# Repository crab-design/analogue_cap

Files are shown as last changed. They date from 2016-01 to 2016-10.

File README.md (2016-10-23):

##What is it?

The analogue cap was designed in response to the release of the raspberry pi zero. For a low cost it helps to break out the analogue outputs from the zero. The analogue ports it provides are stereo audio, composite and VGA. All connectors are aligned to the same edge as the Zero's existing connectors. The board is ideal if you want to utilize a computer monitor, especially if it has built in speakers like many 'multimedia' TFT screens that now cost very little second hand.

Excluding the composite output it will also work on any Raspberry Pi that has the 40 pin GPIO header [ Raspberry Pi A/B+ and the Raspberry Pi B2 ] It
It is a kit

To make it as cheap as possible and easy to adapt for different purposes it is a kit / bare PCB that uses only through-hole components. Due to a lack of space all components are folded this may make it a little fiddly to construct if you have less experience but it is not too hard.

What this means though is that you can choose which way up the cap is mounted, if you what the VGA or not and if you are building into an enclosure the pads can be directly soldered.

the BOM is as follows

    1 x VGA socket
    1 x RCA phono
    1 x 3.5mm Socket
    1 x 40 way socket
    1 x 4 way socket
    1 x PCB
    4 x diodes
    24 x Resistors
    4 x Capacitors

##Enabling the outputs

Please see the setup folder for more information

Due to space and cost the cap does not have auto recognition EEPROM as defined by the HAT specification. It has to be set up by editing the config.txt and adding files to the /boot/ partition.

For VGA it uses Gert van loo's VGA666 hack which uses a passive resistor network to perform the Digital to Analogue conversion. The pins it uses are mapped differently (mode 6 instead of 5) to allow for the audio to also be broken out of the GPIO header. To activate VGA an 'overlay' has to be added to the configuration files of the boot partition. These will be provided in the Github repository.

Analogue audio is the same as the circuit on the Raspberry Pi B+ schematic, but instead the output comes from the GPIO. To activate another 'overlay' is used that comes with the default Rasbian distribution (pwm-2chan-overlay) If this and the VGA is activated only 4 GPIO pins will remain.

The composite is simply an extension of the new breakout pins next to the the Zero's GPIO header, it is connected by its own socket when the cap is pushed on.

The parts activated are up to the user by simply disabling and enabling parts in the config.txt file.

Thankyou for looking, I hope someone will find it useful especially those with lots of old VGA screens hanging around!

Copyright © 2016 Clacktronics

This document and the related files are free: you can redistribute it and/or modify it under the terms of the GNU General Public License as published by the Free Software Foundation, either version 3 of the License, or (at your option) any later version.

This program is distributed in the hope that it will be useful, but WITHOUT ANY WARRANTY; without even the implied warranty of MERCHANTABILITY or FITNESS FOR A PARTICULAR PURPOSE.  See the GNU General Public License for more details.

You should have received a copy of the GNU General Public License along with this document.  If not, see <http://www.gnu.org/licenses/>.

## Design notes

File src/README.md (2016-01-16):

## VGA666 overlays

These files are a copy of the vga666 overlay found in the Raspberry Pi repository [vga666-overlay.dts](https://github.com/raspberrypi/linux/blob/rpi-4.1.y/arch/arm/boot/dts/overlays/vga666-overlay.dts), they have had the pins changed to match the different modes of the GPIO LCD mode as used by the VGA666 board and this analogue board.

information about compiling and editing them can be found on the [Raspberry Pi website](https://www.raspberrypi.org/documentation/configuration/device-tree.md)

to compile (in Rasbian) use the following steps, install the dtc-compiler

`sudo apt-get install device-tree-compiler`

then use the following command `-I dts` defines the source type `-O is the output type` then `-o output.dtb` is the output file you want to make and then the `source.dts` is the file you want to compile.

`dtc -I dts -O dtb -o output.dtb source.dts`

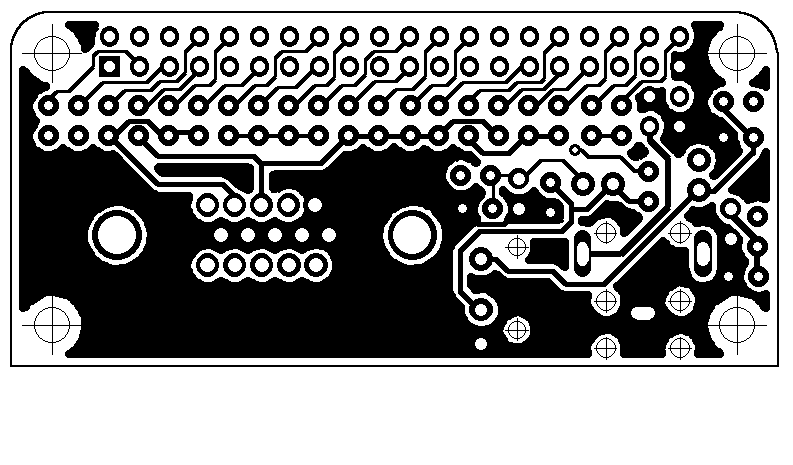
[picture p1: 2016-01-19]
PCB/bitmap/top.bmp

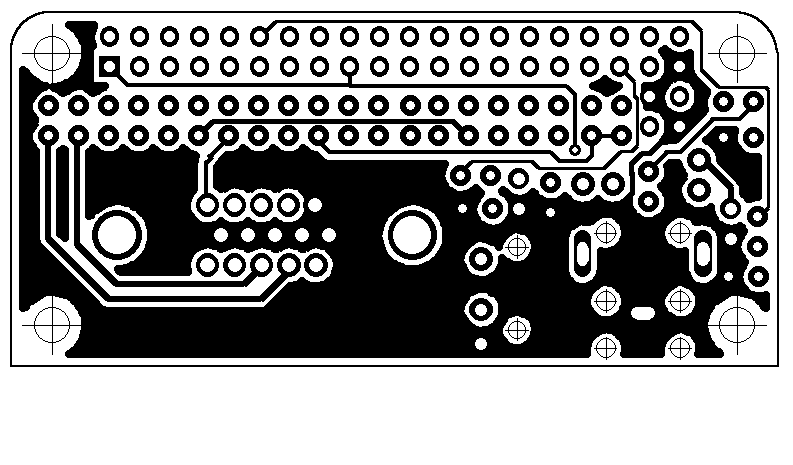
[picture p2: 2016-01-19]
PCB/bitmap/bottom.bmp

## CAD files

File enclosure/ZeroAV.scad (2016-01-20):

// Pi
//translate([0,0,1.6])
//color([0.2,1,0,1])
//roundedRect([65, 30, 1.6], 5, $fn=12);

// Case

color([1,1,1,1])
difference(){
roundedRect([67, 32, 20], 6, $fn=12);
translate([0,0,1.6])roundedRect([65, 30, 20], 5, $fn=12);

rotate([90,0,0])
translate([0,4,10])
{
translate([20,0,0])roundedRect([15,2,10], 1, $fn=12);
translate([-15,0,0])roundedRect([10,2,10], 1, $fn=12);
}




}











module roundedRect(size, radius)
{
	x = size[0];
	y = size[1];
	z = size[2];

	linear_extrude(height=z)
	hull()
	{
		// place 4 circles in the corners, with the given radius
		translate([(-x/2)+(radius/2), (-y/2)+(radius/2), 0])
		circle(r=radius);
	
		translate([(x/2)-(radius/2), (-y/2)+(radius/2), 0])
		circle(r=radius);
	
		translate([(-x/2)+(radius/2), (y/2)-(radius/2), 0])
		circle(r=radius);
	
		translate([(x/2)-(radius/2), (y/2)-(radius/2), 0])
		circle(r=radius);
	}
}

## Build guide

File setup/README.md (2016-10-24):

##Making it work

You can simply download `config.txt` in this directory and put it in your boot folder. Or you can edit `config.txt` on directly the Raspberry Pi.

###VGA
To use the VGA you need to add the file to /boot/overlays/

*If using Rasbian Wheezy or similar you need to copy `crab-vga-overlay.dtb` to the `/boot/overlays` folder
*If you are using Rasbian Jessie you need to copy `crab-vga.dtbo` to the `/boot/overlays/` folder

both files are the same, it is just the naming convention has changed

then the following line should be added to `/boot/config.txt`

```bash 
sudo nano /boot/config.txt
```
then add this line
```
# Setup to make the VGA work
dtoverlay=crab-vga
enable_dpi_lcd=1
dpi_output_format=6

# Makes the VGA the main interface
display_default_lcd=1

# Set resolution of VGA (numbers the the same as HDMI)
dpi_group=2
dpi_mode=16

# On RPi3 Bluetooth has to be disabled 
# for the VGA to work
dtoverlay=pi3-disable-bt
```

`dpi_group` and `dpi_mode` sets the resolution, it is the same setting as HDMI. 
see following link for info, [Raspberry Pi Config.txt](https://www.raspberrypi.org/documentation/configuration/config-txt.md)

###Audio
To make the audio work all you need to do is add the following line to config.txt
```
dtoverlay=pwm-2chan
```

###Composite Out

For composite add this to `/boot/config.txt` this sets the resolution. 
see following link for info, [Raspberry Pi Config.txt](https://www.raspberrypi.org/documentation/configuration/config-txt.md)

```
# Settings SDTV (composite)
sdtv_mode=2
sdtv_aspect=2

# Overscan settings
#overscan_left=16
#overscan_right=16
#overscan_top=16
#overscan_bottom=16
```

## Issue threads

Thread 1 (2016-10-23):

Issues with Raspberry pi boards and new versions of Rasbian

clacktronics, 2016-10-23:
Board does not work with September 2016 Rasbian and Raspberry pi 3

Unknown reason for Rasbian September 2016

Raspberry pi 3 new version of device tree needed for it

clacktronics, 2016-10-23:
fixed issue with new Rasbian, was due to new naming convention.

clacktronics, 2016-10-24:
found how to solve problem with pi 3 , fixed by disabling bluetooth. See setup dir

Closed 2016-10-24.

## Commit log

2016-01-16 template config.txt added
    [config.txt]
2016-01-16 All settings corrected
    [config.txt]
2016-01-19 changed gitignore for adding PCB
2016-01-19 Added PCB
    [AV_Bottom.GBL, AV_BottomMask.GBS, AV_BottomSilk.GBO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]
2016-01-20 started enclosure
    [ZeroAV.scad]
2016-03-08 updated PCB, better ground pads
    [AV_Bottom.GBL, AV_BottomMask.GBS, AV_BottomSilk.GBO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]
2016-10-23 RPi3 update for instructions
    [config.txt]
